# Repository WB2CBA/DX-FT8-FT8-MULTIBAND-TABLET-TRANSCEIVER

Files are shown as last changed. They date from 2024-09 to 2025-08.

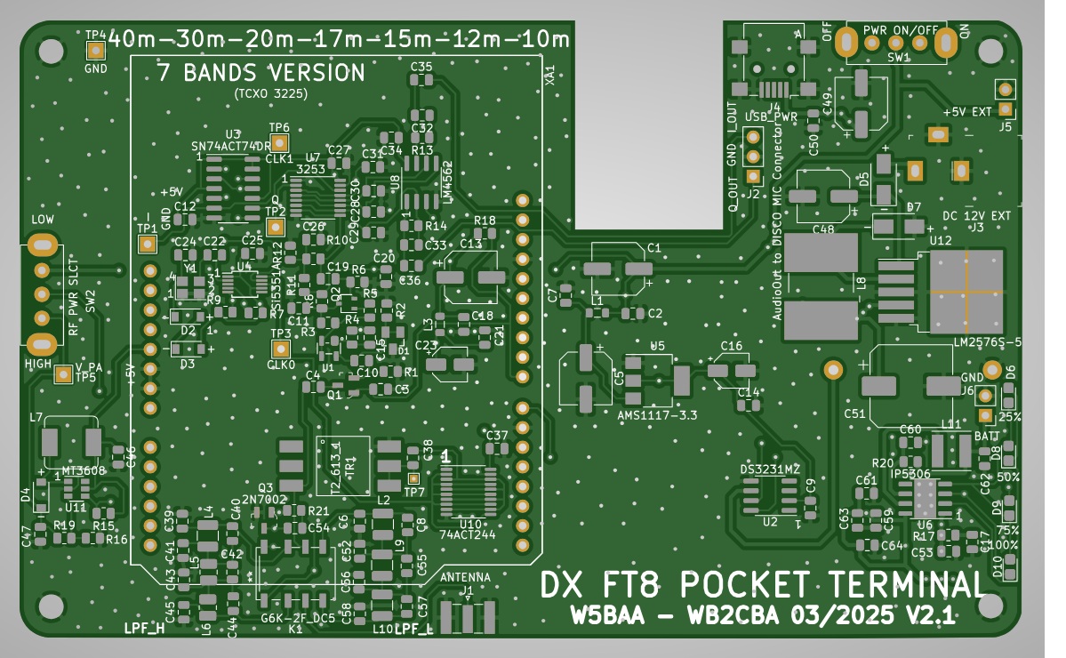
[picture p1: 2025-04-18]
DX FT8 7 Bands with BAT V2.1 component side PCB Layout.jpg

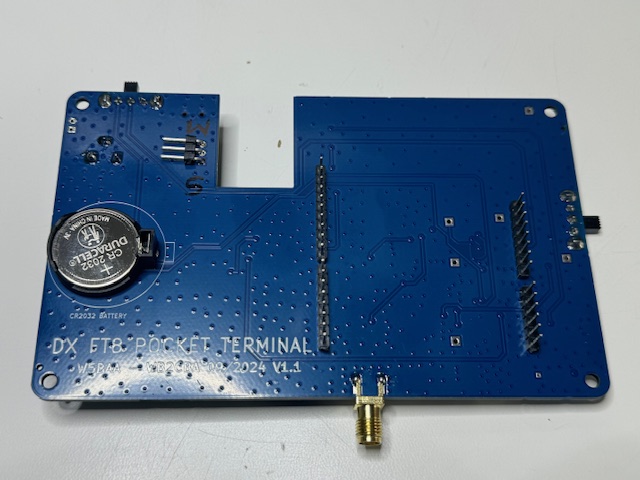
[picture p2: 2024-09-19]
DX FT8 7 BAND PCB INFORMATION/DX FT8 RF BOARD SOLDER SIDE.jpg

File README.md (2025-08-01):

# DX FT8  A MULTIBAND FT8 DIGITAL MODE 5 BANDS OR 7 BANDS TABLET TRANSCEIVER



FOR DX FT8 KIT INFORMATION AND ALL RELATED DISCUSSION YOU CAN JOIN BluQRP FORUM GROUP IN THIS LINK: https://groups.io/g/BluQRP
---------------------------------------------------------------------------------------------------------------------------------------------------
DX FT8 TRANSCEIVER BUILD AND OPERATION GUIDE CAN BE USED FOR OLDER 5 BAND VERSION AND 7 BAND VERSION without Internal Battery. 
---------------------------------------------------------------------------------------------------------------------------------------------------
ALL VERSIONS ARE IDENTICAL IN BUILD AND OPERATION DETAILS EXCEPT THE OPTIONAL INTERNAL BATTERY INSTALLATION ON V2.1 BMS 7 BAND BOARD.
---------------------------------------------------------------------------------------------------------------------------------------------------
DX FT8 TRANSCEIVER OPERATION GUIDE YOUTUBE VIDEO: https://www.youtube.com/watch?v=PcSgQS4a3Tk
----------------------------------------------------------------------------------------------------------------------------------------------------
DX FT8 TRANSCEIVER PROJECT is a collaboration between Charles(Charley)Hill, W5BAA and Barbaros(Barb)Asuroglu, WB2CBA.

DX FT8 Project is brain child of Charles(Charley)Hill, W5BAA. Charley designed and build various versions of GUI based FT8 Transceivers over the years. 

I was lucky enough to collaborate with Charley on 3 different versions of GUI FT8 Transceiver.

DX FT8 is the culmination of all that experience we gained from previous versions.

I can't thank enough Charley for his excellent GUI FT8 Firmware and his perseverance to create a standalone FT8 TABLET Transceiver.

It's a pleasure for me to collaborate with Charley,W5BAA, on hardware side, RF design and PCB design of DX FT8 Transceiver.

DX FT8 is an OPEN SOURCE PROJECT.
---------------------------------
DX FT8 is a FT8 Digital mode capable HF QRPp GUI (Graphical User Interface) based multiband Transceiver.

DX FT8 is abreviation for Digital Xceiver for FT8. 

Main aim of DX FT8 Transceiver Project is to create a highly portable stand-alone FT8 GUI Transceiver. Stand-alone aim is to create a user interface for working FT8 digital mode plus Multiband transceiver packed into one unit. 

This creates an advantage for carrying one GUI based FT8 operation capable Transceiver unit and no longer needs to carry a PC or a laptop or tablet for GUI interface operation for FT8 with a classic transceiver. 

This approach is quite appealing for smaller and lighter setups for backpacking for SOTA or POTA activations or as a travel transceiver with FT8.  

Here are some highlights on DX FT8 Specifications:

-	DX FT8 Transceiver GUI (Graphical User Interface) and processing power comes from ST Micro STM32F746 DISCO Evaluation board. This is a ARM CORTEX based evaluation board for STM32F746 microcontrollers with below outlined specifications: 

-	STM32F746NGH6 Arm® Cortex® core-based microcontroller with 1 Mbyte of Flash memory and 340 Kbytes of RAM, in BGA216 package 

-	4.3 inch RGB 480×272 color LCD-TFT with capacitive touch screen 

-	128-Mbit Quad-SPI Flash memory
 
-	DX FT8 Transceiver RF Board plugs into STM32F746 DISCO evaluation board to form the DX FT8 transceiver. 

-	DX FT8 Transceiver operates on 5 HF bands or 7 Bands depending on PCB type. Design files for both 5 band and 7 bands boards are posted in this github page.

-	These bands are:

For 5 Bands Board:
  
1 – 20m (14.074 MHz)

2- 17m (18.100 MHz)

3- 15m (21.074 MHz)

4- 12m (24.915 MHz)

5- 10m (28.074 MHz)

For 7 Bands Board:
  
1 – 40m (7.074 MHz)

2- 30m (10.136 MHz)

3 – 20m (14.074 MHz)

4- 17m (18.100 MHz)

5- 15m (21.074 MHz)

6- 12m (24.915 MHz)

7- 10m (28.074 MHz)

DX FT8 Transceiver has two RF Power Output Selection, LOW RF POWER and HIGH RF POWER which can be selected with the RF POWER Slide switch on the side of the transceiver.

40m	   372mW	       844mW

30m	   373mW	       843mW

20m	   380mW	       823mW

17m	   354mW	       762mW

15m	   314mW	       654mW

12m	   259mW	       520mW

10m	   231mW	       445mW

-	DX FT8 Transceiver can operate either from 5V USB power bank or any 1000mA capacity USB power source or by using the DC barrel Connector can be powered from 7V to 15V external power supply. A power supply source can be selected with DC POWER SELECT slide switch located on the side of the Transceiver. 

-	DX FT8 TRANSCEIVER uses an unconventional RF power Amplifier consisting of a TTL octal buffer IC and step up RF Transformer. There is no conventional MOSFET PA transistors. This creates an extremely resilient RF PA for failure due to high SWR or no antenna accidental operations.  This is an advantage for portable operations as antenna conditions can vary.

-	DX FT8 TRANSCEIVER incorporates a TAYLOE detector based Qudarature Sampling detector receiver with a high gain RF Preamplifier which outputs an I and Q phase output to STM32F746 DISCO board which generates true Upper Side Band (USB) SSB receive signal. 

-	A short video of DX FT8 in action:
  https://www.youtube.com/watch?v=8b2WOxESAVU
----------------------------------------------------------------------------------------------------------------------------------

DX FT8 FIRMWARE UPDATE HISTORY:

----------------------------------------------------------------------------------------------------------------------------------
DX FT8 Project Firmware Version 2.0.0 Release Notes: 29 JULY 2025
----------------------------------------------------------------------------------------------------------------------------------
V2.0.0 includes four major improvements over V1.9.7:

TX Queue: You can now click on multiple received messages in either QSO or Becn mode. The firmware will queue appropriate responses, automatically sort them, and transmit the best one for you. 
    
When calling CQ, replies from multiple stations will be queued automatically as well.

On Device Editing: Six buttons were added under the "Tune" page.

click one of these buttons to activate editing window:

CALL: YourCall or YourCall/P (Note: other prefix/suffix formats aren’t supported)

GRID: YourGrid

FREQ: 7074/.../28074 (optional) (Note: the firmware doesn’t validate frequency; make sure it's within the band. Use Band-/Band+ to switch bands.)

F1: Free Text 1 (optional) (Free Text also works for "CQ [A-ZZZZ] [YourCall] [YourGrid]")

F2: Free Text 2 (optional)

COM: Comments for the session (optional) (This will be added to each QSO in the .ADIF file)

Tap the same button again to finish editing and changes are saved to StationData.ini.

Auto-Generated StationData.ini: If no StationData.ini file is found on the SD card, the firmware will create one using an internal template. Just enter your callsign and grid on the device and you're ready to go—even with a blank SD card.

Showing worked QSOs for the current session: Tap the middle-right side of the screen to view worked QSOs, tap again to view the next page. (Tips: take photos as a backup in case the SD card fails)

--------------------------------------------------------------------
FOR SOURCE CODE PLEASE VISIT:
    https://github.com/chillmf/DX-FT8-Transceiver-Source-Code_V2
--------------------------------------------------------------------

DX FT8 3D PRINTED CASE FILES ADDED. A big Thank You to Dave,ZL1DMM for his excellent 3D case design.

 
------------------------------------------------------------------------------------------------------------------------------------------

- ACKNOWLEDGEMENT:

- We would like to thank Paul Winwood, G8KIG, Zhenxing han, N6HAN and Wei Cheng, AG6AQ for their contributions to develop and adding new features and cleaning the code of DX FT8 Firmware.

- DX-FT8 Firmware is inspired by work done by Karlis Goba, YL3JG. Here is a link to his website: https://github.com/kgoba/ft8_lib.

--------------------------------------------------------------------------------------------------------------------------------

---------------------------------------------------------------------------------------------------------------------------------
DUE TO TARIFFS DX FT8 KITS ARE GETTING EXTREMELY EXPENSIVE. WE STOPPED KITTING FOR THE TIME BEING TO WAIT FOR THE TARIFF SITUATION TO SETTLE. 
NO KITS WILL BE OFFERED AS OF 05/12/2025 UNTIL FURTHER NOTICE. SORRY FOR THE INCONVENIENCE. 
----------------------------------------------------------------------------------------------------------------------------------------------

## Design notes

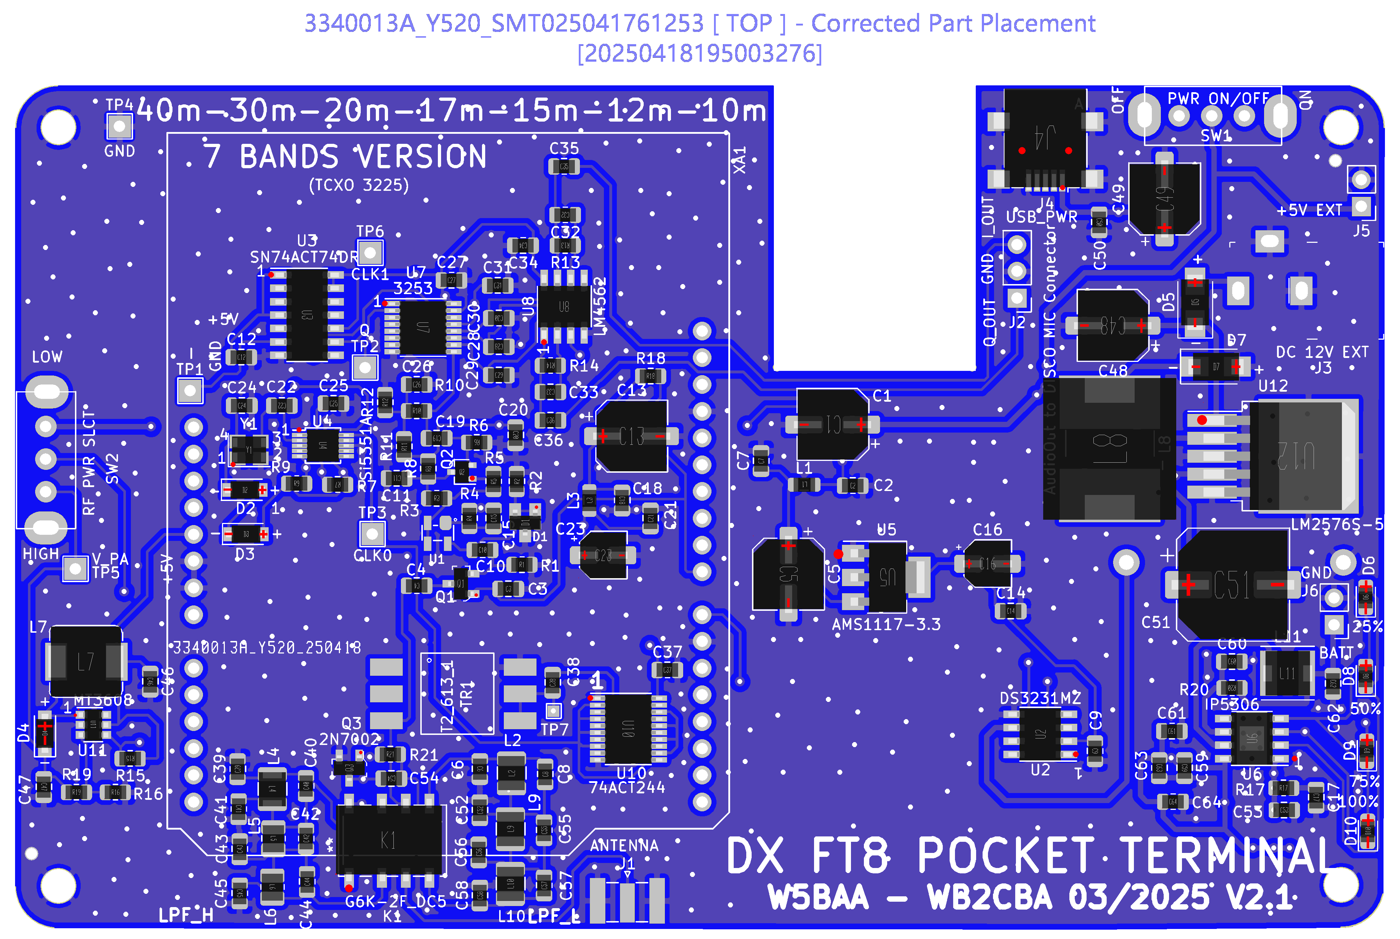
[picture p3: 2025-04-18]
DX FT8 7 BAND BMS V2.1 DFM ANALYSIS.png

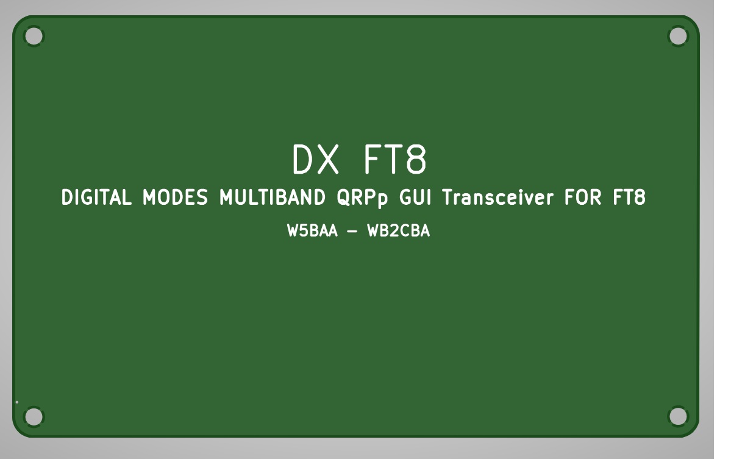
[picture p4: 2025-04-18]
DX FT8 7 Bands with BAT V2.1 BOTTOM PCB Layout.jpg

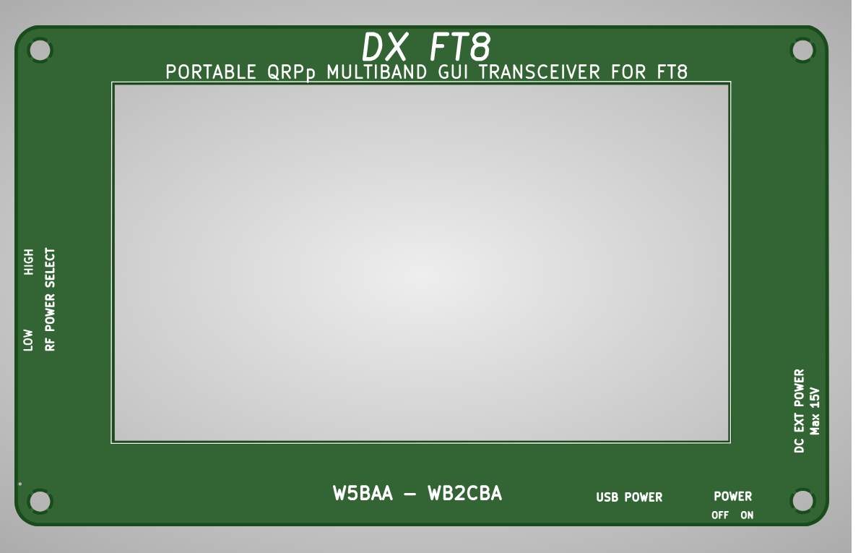
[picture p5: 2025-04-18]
DX FT8 7 Bands with BAT V2.1 TOP PCB Layout.jpg

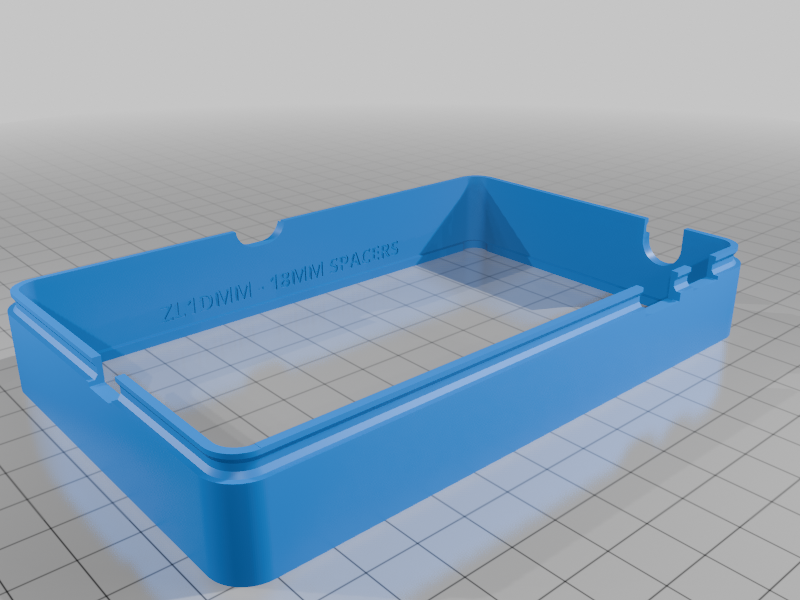
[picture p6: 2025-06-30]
DX FT8 3D CASE FILES/DXFT8_-_Case_Bottom_18mm_Bottom_Layer_Spacers.png

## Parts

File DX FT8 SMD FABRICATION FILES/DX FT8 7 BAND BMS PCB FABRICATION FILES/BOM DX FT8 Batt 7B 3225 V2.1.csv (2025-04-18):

Comment | Designator | Footprint | LCSC
47nF | C11,C20 | Capacitor_SMD:C_0805_2012Metric | C53134
100nF | C2,C7,C9,C12,C14,C18,C21,C22,C24,C25,C26,C27,C34,C37,C38,C50,C64 | Capacitor_SMD:C_0805_2012Metric | C28233
2.2nF | C15 | Capacitor_SMD:C_0805_2012Metric | C28260
10uF/16V | C16,C23 | Capacitor_SMD:CP_Elec_4x5.4 | C4747968
10uF | C17,C53 | Capacitor_SMD:C_0805_2012Metric | C15850
470nF | C28,C29,C30,C31,C54 | Capacitor_SMD:C_0805_2012Metric | C13967
1nF | C32,C33 | Capacitor_SMD:C_0805_2012Metric | C46653
1uF | C35,C36 | Capacitor_SMD:C_0805_2012Metric | C28323
100pF | C39 | Capacitor_SMD:C_0805_2012Metric | C37456
10nF | C3,C4,C10,C19 | Capacitor_SMD:C_0805_2012Metric | C1710
12pF | C40 | Capacitor_SMD:C_0805_2012Metric | C1792
180pF | C41 | Capacitor_SMD:C_0805_2012Metric | C3846504
150pF | C43 | Capacitor_SMD:C_0805_2012Metric | C107111
39pF | C8,C44 | Capacitor_SMD:C_0805_2012Metric | C107117
56pF | C42,C45 | Capacitor_SMD:C_0805_2012Metric | C1828
22uF | C46,C47,C59,C60,C61,C62,C63 | Capacitor_SMD:C_0805_2012Metric | C45783
100uF/16V | C1,C5,C13,C48,C49 | Capacitor_SMD:CP_Elec_6.3x7.7 | C3339
1000uF/16V | C51 | Capacitor_SMD:CP_Elec_10x10.5 | C970714
270pF | C52 | Capacitor_SMD:C_0805_2012Metric | C107106
82pF | C57 | Capacitor_SMD:C_0805_2012Metric | C113833
120pF | C55,C58 | Capacitor_SMD:C_0805_2012Metric | C527208
220pF | C6,C56 | Capacitor_SMD:C_0805_2012Metric | C107112
BAS70-04 | D1 | BAS70-04:SOT23 | C150242
100% | D10 | Diode_SMD:D_0805_2012Metric_Castellated | C84256
1N4148 | D2,D3 | Diode_SMD:D_SOD-123 | C81598
1N5817 | D4 | Diode_SMD:D_SOD-123 | C727113
25% | D6 | Diode_SMD:D_0805_2012Metric_Castellated | C84256
SS34 | D5,D7 | Diode_SMD:D_SMA | C8678
50% | D8 | Diode_SMD:D_0805_2012Metric_Castellated | C84256
75% | D9 | Diode_SMD:D_0805_2012Metric_Castellated | C84256
USB_PWR | J4 | Connector_USB:USB_Mini-B_Lumberg_2486_01_Horizontal | C2681563
G6K-2F_DC5 | K1 | G6K_2F:G6K-2F_Cor | C47190
100uH | L1,L3 | Inductor_SMD:L_0805_2012Metric | C223180
1uH | L11 | Inductor_SMD:L_Taiyo-Yuden_NR-50xx | C133189
560nH | L2 | Inductor_SMD:L_1210_3225Metric | C89030
330nH | L4 | Inductor_SMD:L_1210_3225Metric | C295307
270nH | L5,L6 | Inductor_SMD:L_1008_2520Metric | C295305
22uH | L7 | SubW:SubW_PWR_INDUCTOR | C497873
100uH | L8 | ADX_FOOTPRINT_LIBRARY:L_Bourns-SRN8040_8x8.15mm-MOD2 | C408533
470nH | L9,L10 | Inductor_SMD:L_1210_3225Metric | C89029
BSS123 | Q1 | digikey-footprints:SOT-23-3 | C513249
BFR93 | Q2 | Package_TO_SOT_SMD:SOT-323_SC-70 | C151481
2N7002 | Q3 | digikey-footprints:SOT-23-3 | C8545
1k | R1,R10 | Resistor_SMD:R_0805_2012Metric | C17513
10k | R11,R12 | Resistor_SMD:R_0805_2012Metric | C17414
2.7k | R13,R14 | Resistor_SMD:R_0805_2012Metric | C17530
3.9k | R15,R18,R21 | Resistor_SMD:R_0805_2012Metric | C17614
1.2k | R16 | Resistor_SMD:R_0805_2012Metric | C17379
2 ohm | R17 | Resistor_SMD:R_0805_2012Metric | C17606
12k | R19 | Resistor_SMD:R_0805_2012Metric | C17444
100k | R2 | Resistor_SMD:R_0805_2012Metric | C149504
0.5 ohm | R20 | Resistor_SMD:R_0805_2012Metric | C158119
470 | R3 | Resistor_SMD:R_0805_2012Metric | C17710
100 | R4 | Resistor_SMD:R_0805_2012Metric | C17408
22 | R5 | Resistor_SMD:R_0805_2012Metric | C17561
680 | R6 | Resistor_SMD:R_0805_2012Metric | C17798
4.7k | R7,R9 | Resistor_SMD:R_0805_2012Metric | C17673
33 | R8 | Resistor_SMD:R_0805_2012Metric | C17634
74ACT244 | U10 | Package_SO:TSSOP-20_4.4x6.5mm_P0.65mm | C6930
MT3608 | U11 | Package_TO_SOT_SMD:SOT-23-6 | C84817
LM2576S-5 | U12 | Package_TO_SOT_SMD:TO-263-5_TabPin3 | C347413
DS3231MZ | U2 | Package_SO:SOIC-8_3.9x4.9mm_P1.27mm | C107410
SN74ACT74DR | U3 | Package_SO:SOIC-14_3.9x8.7mm_P1.27mm | C6933
Si5351A | U4 | Package_SO:MSOP-10_3x3mm_P0.5mm | C504891
AMS1117-3.3 | U5 | Package_TO_SOT_SMD:SOT-223-3_TabPin2 | C6186
IP5306 | U6 | POCKET ATU V1:SO-8_3.9x4.9mm_P1.27mm | C181692
3253 | U7 | Package_SO:TSSOP-16_4.4x5mm_P0.65mm | C424399
LM4562 | U8 | Package_SO:SOIC-8_3.9x4.9mm_P1.27mm | C57367
26Mhz | Y1 | Crystal:Crystal_SMD_SeikoEpson_FA238-4Pin_3.2x2.5mm | C213404

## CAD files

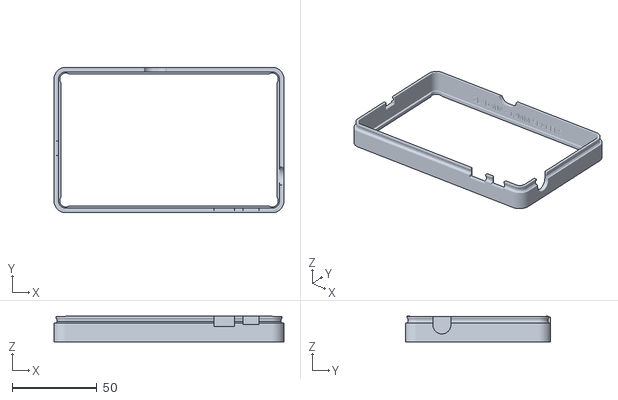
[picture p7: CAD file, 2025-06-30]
DX FT8 3D CASE FILES/DXFT8_-_Case_Bottom_12mm_Bottom_Layer_Spacers.stl
136.0 x 86.0 x 15.2

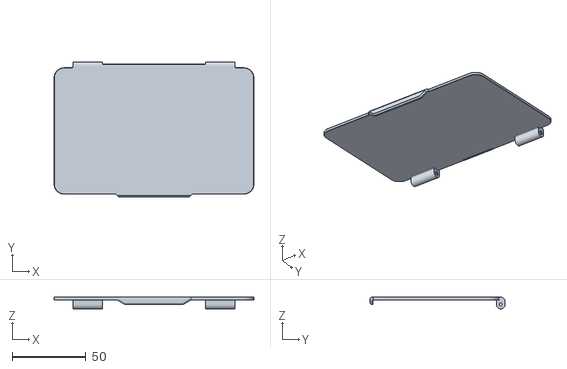
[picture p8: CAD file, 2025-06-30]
DX FT8 3D CASE FILES/DXFT8_-_Case_Door.stl
136.0 x 92.0 x 8.00

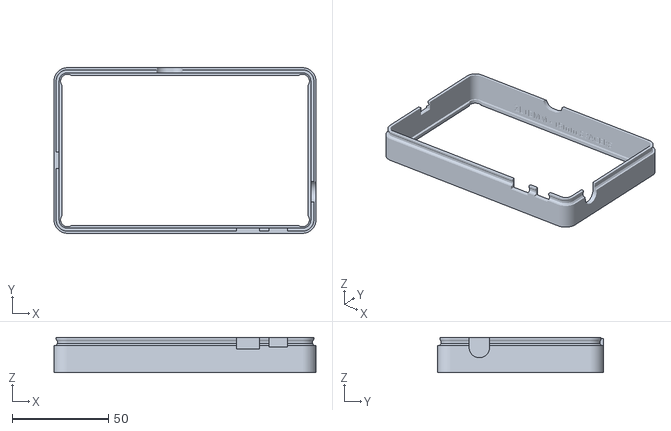
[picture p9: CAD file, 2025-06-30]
DX FT8 3D CASE FILES/DXFT8_-_Case_Bottom_15mm_Bottom_Layer_Spacers.stl
136.0 x 86.0 x 18.2

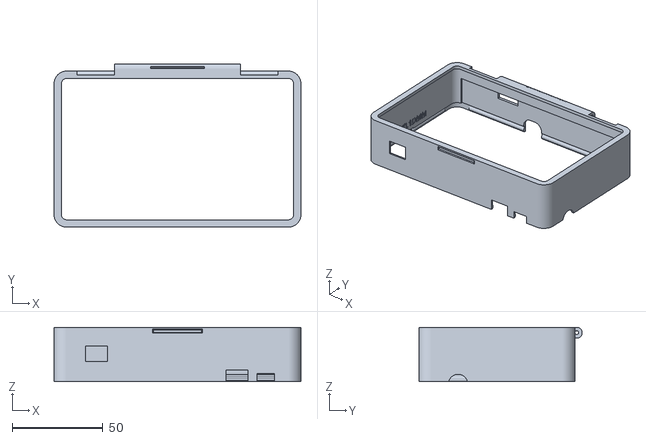
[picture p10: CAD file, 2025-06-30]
DX FT8 3D CASE FILES/DXFT8_-_Case_Top.stl
136.0 x 90.0 x 30.0

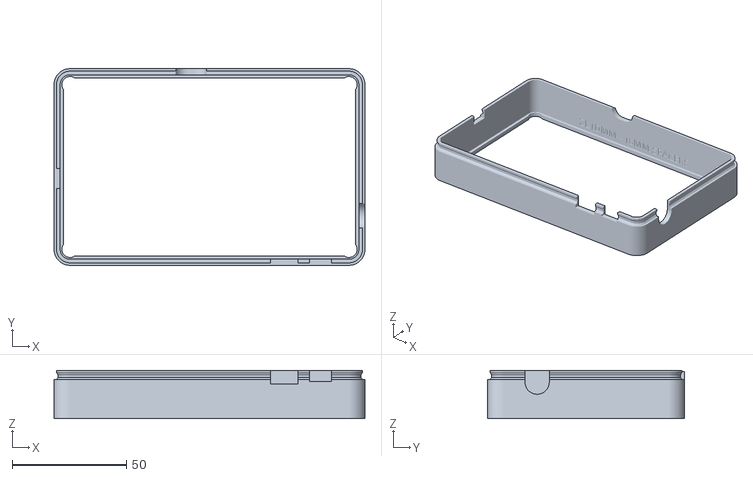
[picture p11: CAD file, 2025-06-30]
DX FT8 3D CASE FILES/DXFT8_-_Case_Bottom_18mm_Bottom_Layer_Spacers.stl
136.0 x 86.0 x 21.2

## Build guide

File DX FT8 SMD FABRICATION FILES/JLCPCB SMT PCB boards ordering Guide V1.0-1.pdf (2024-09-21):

# SMT PCB boards - JLCPCB ordering guide:

Now let’s talk about the most important subject! How we are going to get these SMD boards manufactured! Here is a short guide for ordering SMD manufactured boards from JLCPCB!

Surface mount parts might be intimidating for most of us. They need healthy eyes and steady hands to solder. This SMT pcb manufacturing service cures that problem by manufacturing PCBs and installing all smd parts on them in a controlled factory environment! An example of cost for this service: uSDX SOTA Main board will cost you less than 15 US Dollars each for a batch of 10 PCB orders including DHL shipping! This means a PCB with 85% of parts assembled including that SI5351 beast! The trick is the more units of pcb you order the less you pay for one pcb in cost.

The reason for that is there are certain one time fee costs JLCPCB adds to their invoice. Those are SMT setting up fee, extended parts fee etc. These are one time cost charges for each pcb order batch. So if we order 5 pieces of pcb that surcharge cost will be shared by 5 pcbs. If we order 30 pcbs then that surcharge will be divided by 30 and will be less per pcb. That’s why it is always order pcbs in larger quantities as a group buy. Ok how we will do this smt ordering business!

I’ll explain this as simple as possible in steps:

1- We will need Production files:
In order to place an order a SMT manufactured PCB from JLCPCB we need three files
– GERBER file (contains all the files to manufacture the PCB board itself)
– BOM File(contains all smd parts, their smd footprints and JLCPCB stock numbers for each part)
– Foot print position file (it is also called as centroid file – coordinates of each smd part on the pcb for pick and place robot)

All these files are included in each boards ZIP file under production file directory.

2- Create an account on www.jlcpcb.com. Follow instructions on their site.

3- After creating your account with all your credentials click on instant quote button

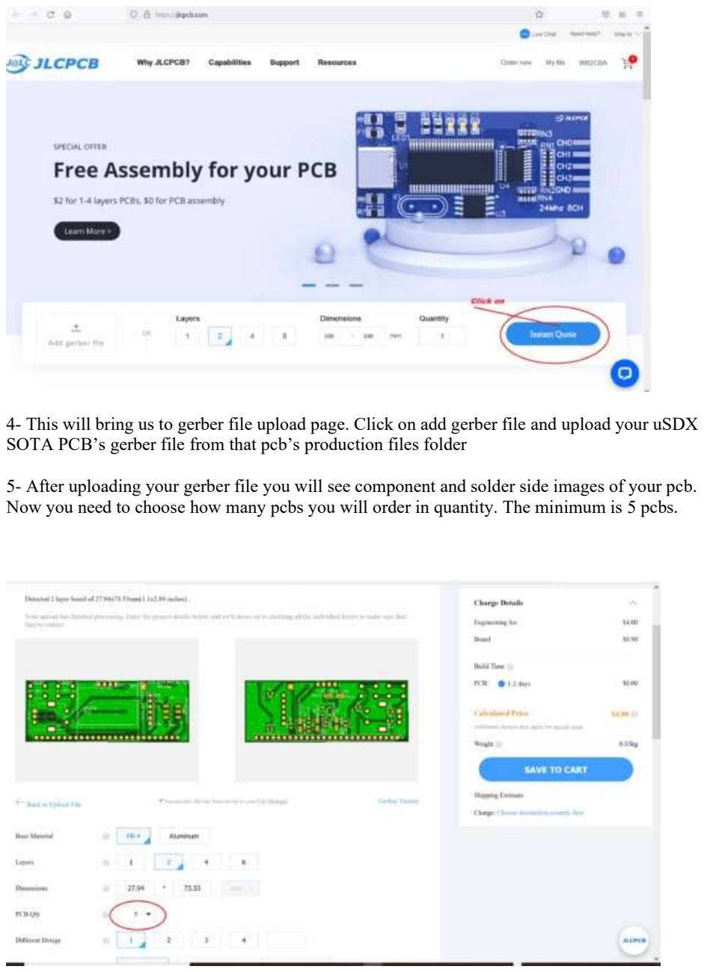
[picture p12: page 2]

4- This will bring us to gerber file upload page. Click on add gerber file and upload your uSDX SOTA PCB’s gerber file from that pcb’s production files folder

5- After uploading your gerber file you will see component and solder side images of your pcb. Now you need to choose how many pcbs you will order in quantity. The minimum is 5 pcbs.

6- Now scroll down the same gerber upload page until you see the Free SMT Assembly for your PCB slide switch which should be light grey inactive position. Now slide it to activate. You should see below screen with top and bottom sides of your PCB. In this case I used uSDX SOTA 128×64 OLED Display as an example. In this display smd populated side is bottom side so I chose assemble bottom side. Now without touching anything else first click on Confirm then click on NEXT.

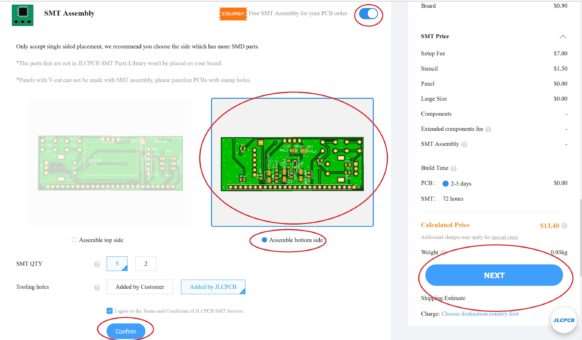
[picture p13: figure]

7- Now we will come to this next screen after clicking on NEXT. This is where we upload our BOM file and footprint position file which is marked as CPL button. These files are in your PCB’s production files. First click on Add BOM File button and upload BOM file from production files folder. Then click on Add CPL File Button and upload your footprint position file from your PCB’s production files.

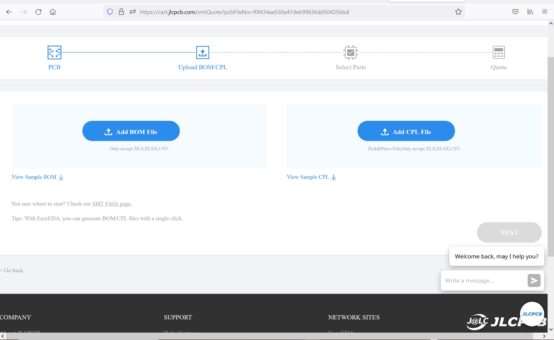
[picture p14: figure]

8- After uploading BOM and CPL files this is the screen which shows all the components of our PCB for SMT manufacturing. This table will show all the component part numbers, total number of each component that will be used for the whole batch of PCBs. Also total cost of each part for the whole batch of PCB order.

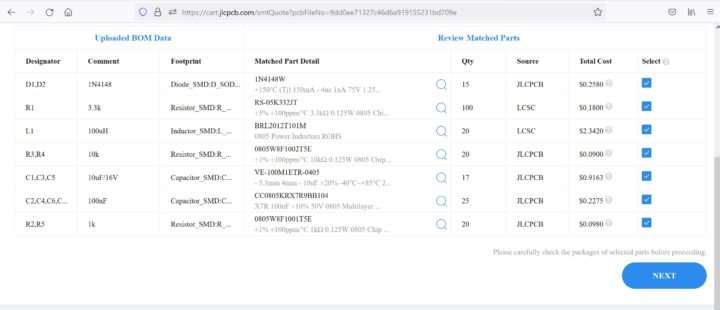
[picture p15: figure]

The most important column in this table is those blue check marks. If you see a blue check mark then it tells you that they have your components and those components have enough stock to manufacture your boards! If one or more parts is not in stock which can happen nowadays as there is chip shortage going on you might get an inventory shortage warning in place of blue check mark. Now JLCPCB does not have that part in stock and can’t pick and place that part and that part will be omitted from pick and place manufacturing. It’s not the end of the world! You can still get your pcb manufactured and hand solder those parts when you receive your pcbs.

Here is an example for that:

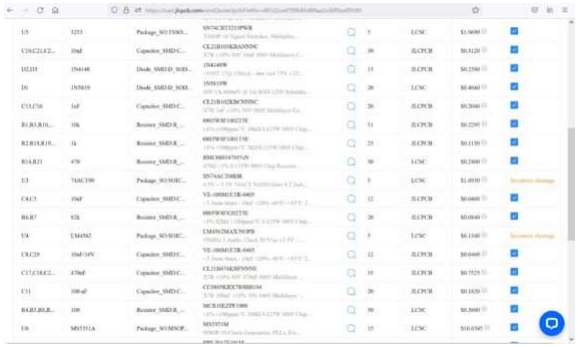
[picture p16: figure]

This is parts list for uSDX SOTA Main PCB. Two parts, 74ACT00DWR and LM4562 is out of stock. The rest of the parts are in stock so no problem with them. We will just order the PCBS and hand solder those parts afterwards. They are easy to solder smd parts.
Now click on NEXT to go to the next ordering screen.

9- This is the next screenshot you will come across which shows your PCB and virtual pick and place finished product layout of your pcb. There might be orientation errors in this PCB virtual parts layout time to time, don’t worry about that. JLCPCB will review your pcb layout and pick and place file and then match those positions. After you ordered your PCB for SMT manufacturing they will review it and correct those mismatches. After this review when you access your account you will see a DFM file icon. If you click on that it will show your previous and manufacturing virtual corrected layout.

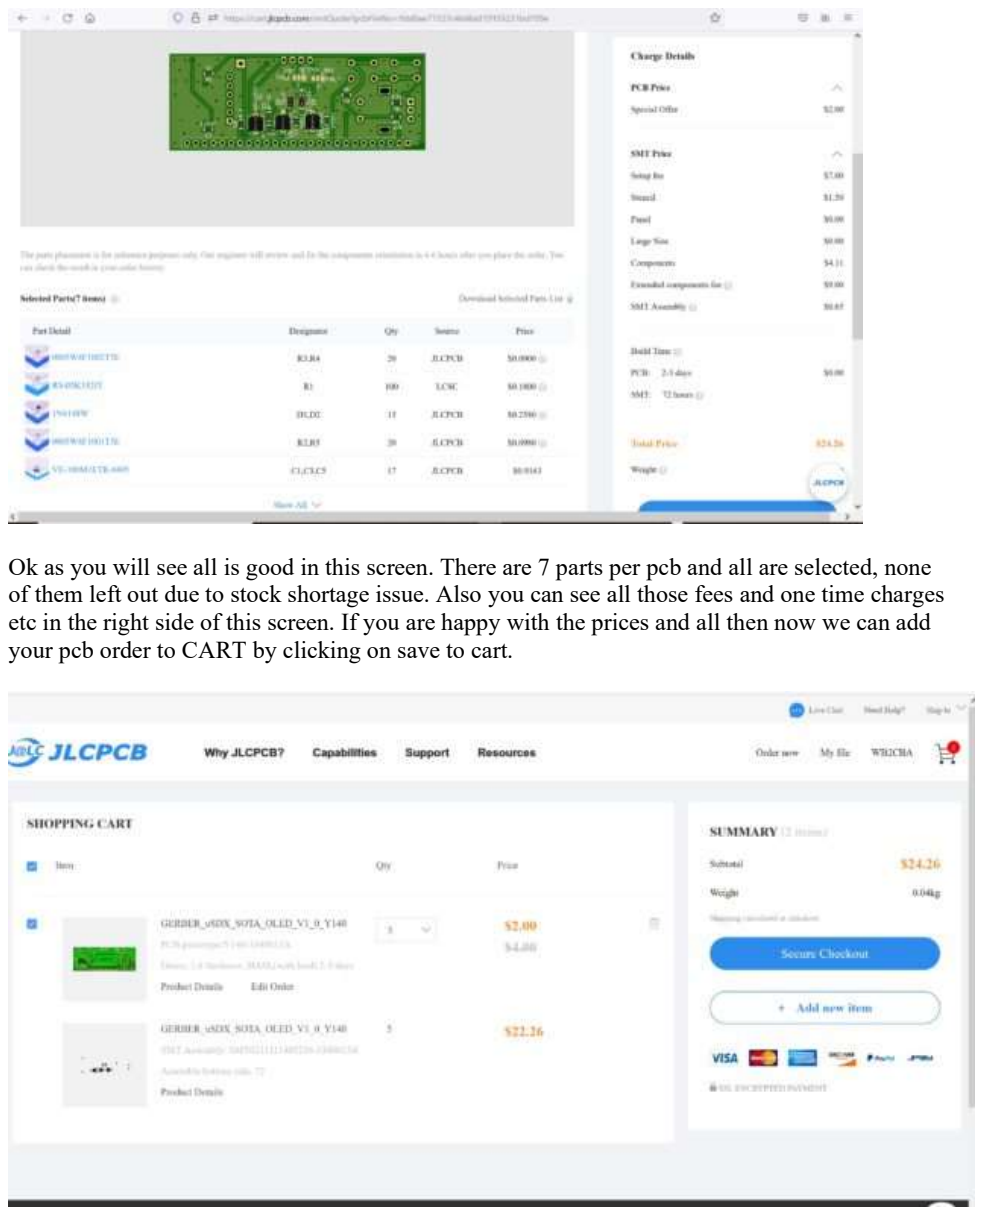
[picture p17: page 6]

Ok as you will see all is good in this screen. There are 7 parts per pcb and all are selected, none of them left out due to stock shortage issue. Also you can see all those fees and one time charges etc in the right side of this screen. If you are happy with the prices and all then now we can add your pcb order to CART by clicking on save to cart.

This CART screen will show your total cost for that ordered pcb batch. Now press on secure checkout and follow the procedure by verifying your address then shipment type and then payment etc.

Now let’s talk again about our nightmare case where some of the parts were out of stock!

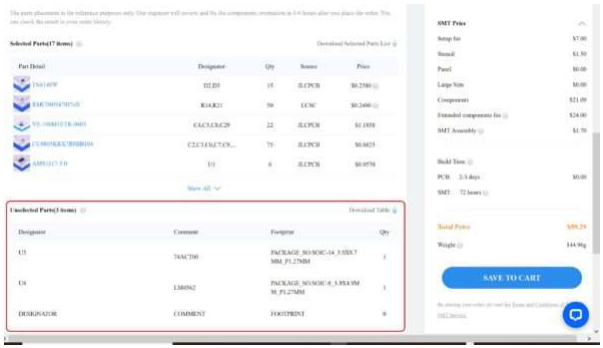
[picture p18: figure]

In uSDX SOTA Main board PCB case two parts were out of stock and we still advanced the order and clicked next. Now as outlined in red box those parts are out of production and not listed on main parts list and will not be shown on virtual smt mounted pcb layout. We can still go ahead with the order and save to cart and get main board pcbs manufactured and when we outsource those parts we can hand solder them. It’s not the end of the world!

Personally I encourage fellow DIY lover hams to give it a try on ordering uSDX SOTA boards smt manufactured from JLCPCB. You will be surprised how cheap they will be for an order of 10 boards. Even with minimum 5 boards is reasonable price. The biggest benefit is that 85% of the transceiver rig is coming to your door step already soldered in!

Barb WB2CBA
12/05/2021 NY, USA

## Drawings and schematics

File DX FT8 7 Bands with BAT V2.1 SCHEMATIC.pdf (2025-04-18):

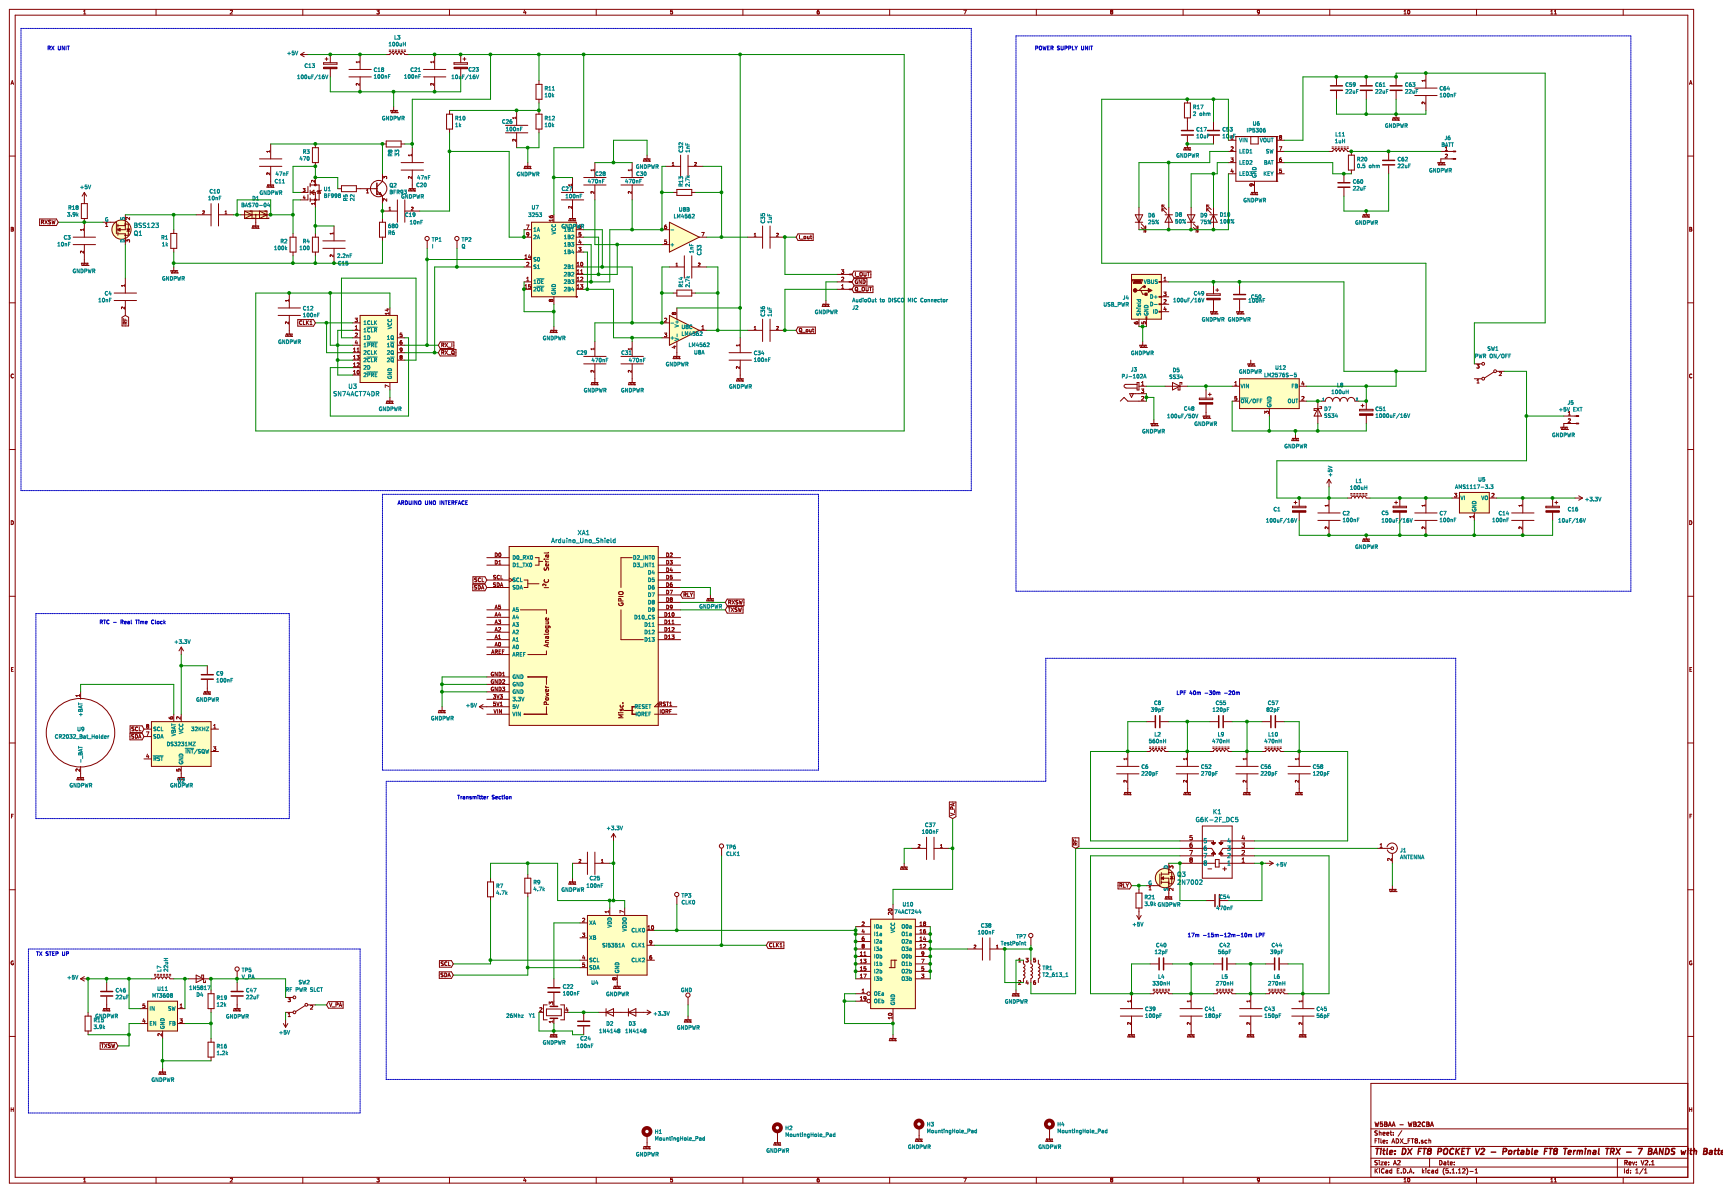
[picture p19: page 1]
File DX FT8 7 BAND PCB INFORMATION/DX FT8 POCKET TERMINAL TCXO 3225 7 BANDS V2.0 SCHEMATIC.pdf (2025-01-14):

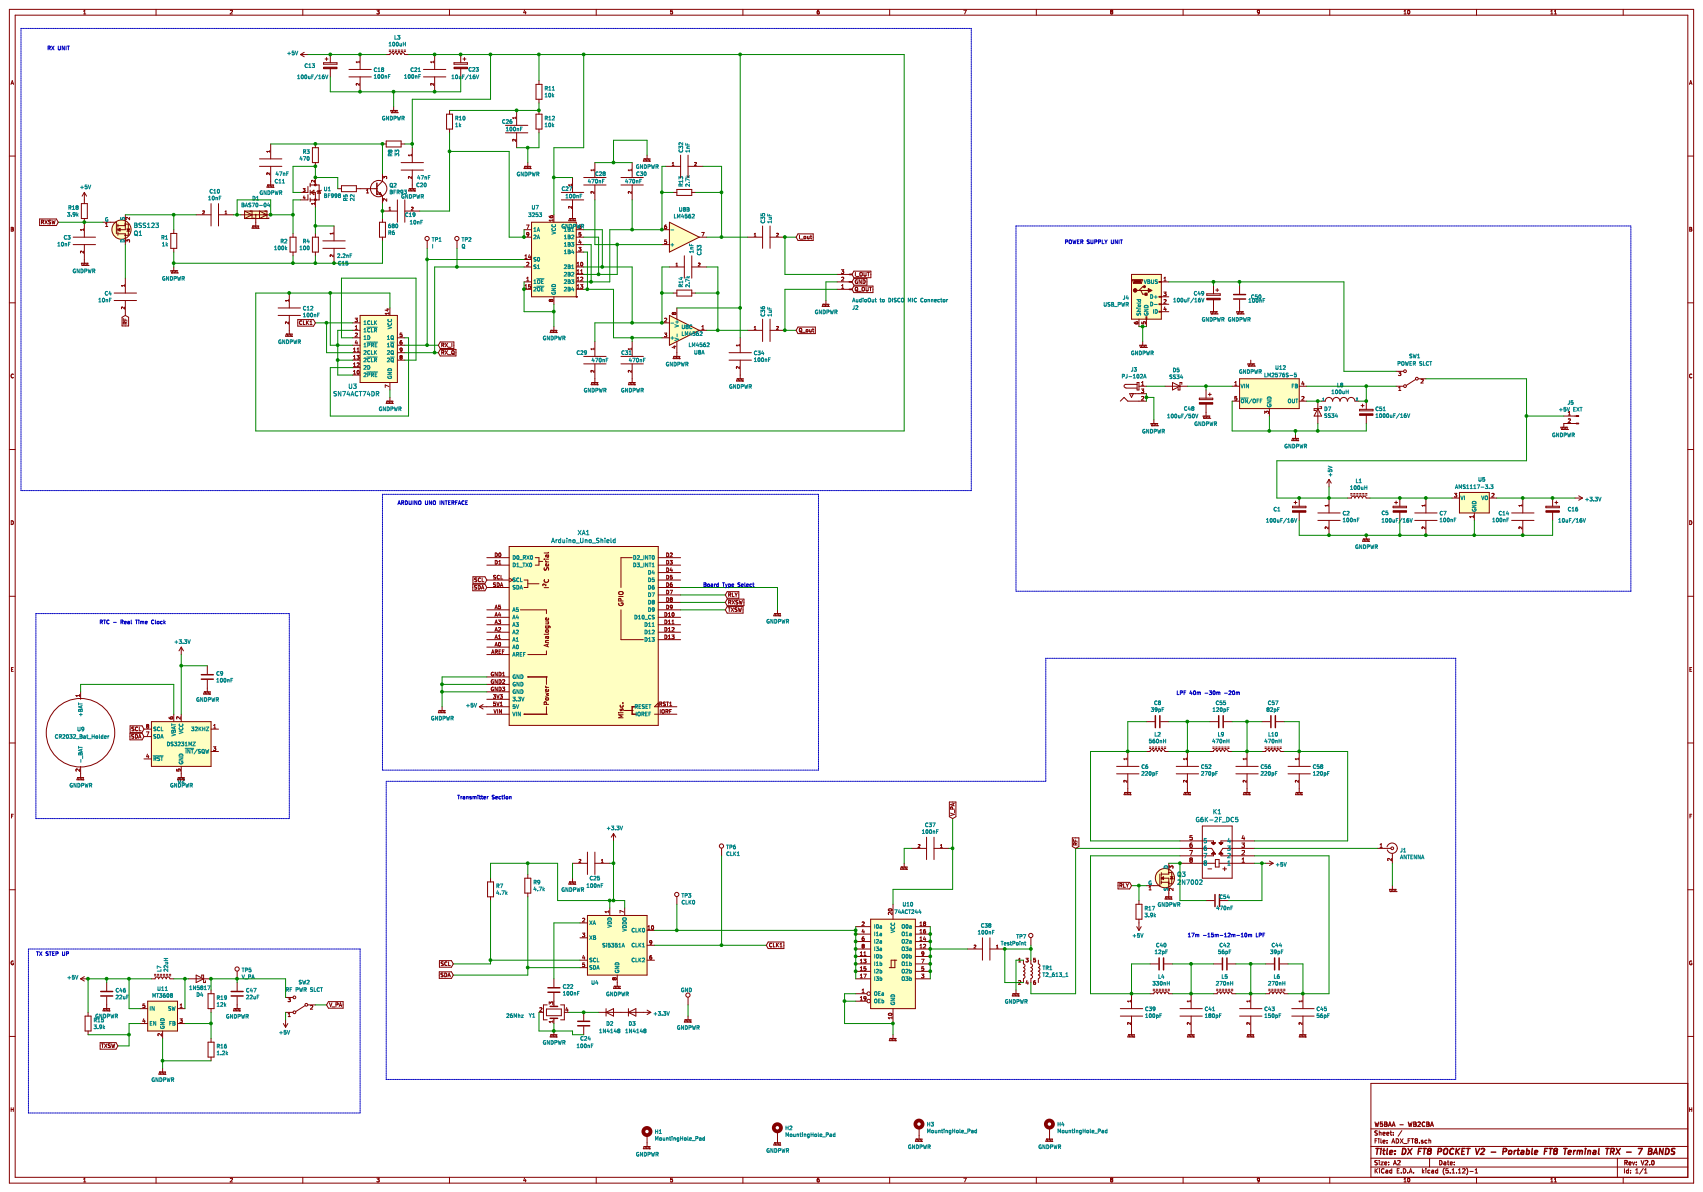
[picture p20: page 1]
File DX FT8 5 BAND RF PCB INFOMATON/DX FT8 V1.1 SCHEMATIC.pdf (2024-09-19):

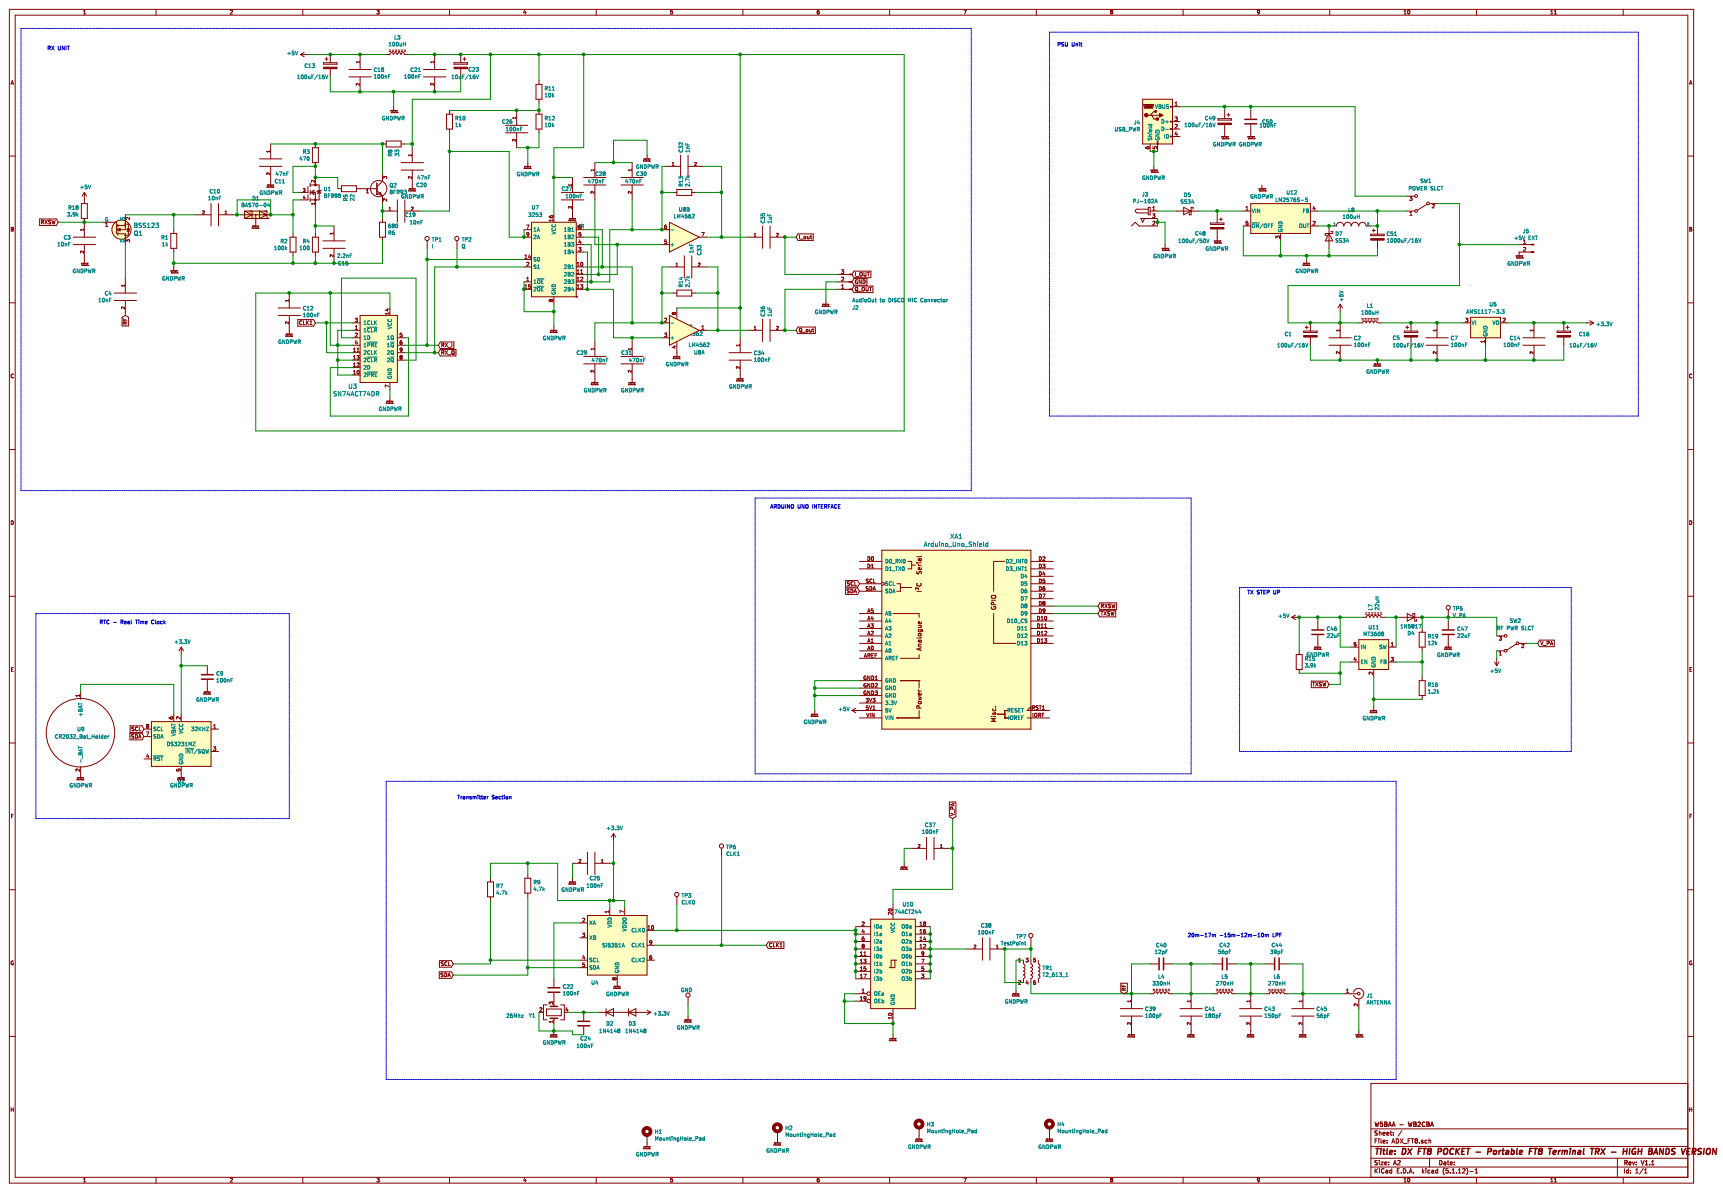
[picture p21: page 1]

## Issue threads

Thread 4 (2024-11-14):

Power requirements

RChadwick7, 2024-11-14:
I don't have a DX-FT8 yet but it's on the way. I have a question about power. I'll probably add a Li-Ion battery and BMS. The docs say 5V at 1A. Is that a minimum? Should I provide 2+ Amps? Will a higher voltage be better, or will a regulator just knock it down to 5V?

RChadwick7, 2024-11-17:
Nevermind, I found the schematic and found my answers. 5V.

Closed 2024-11-17.

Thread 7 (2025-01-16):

Battery Management on board

RChadwick7, 2025-01-16:
There appears to be plenty of room to tuck a thin Li-Po battery between the layers. It would be extra beneficial if there was a BMS on board, or even just unpopulated pads so those of us who want to add a battery can do so. There are plenty of single chips that will handle charging, discharge protection, stepping up to 5V, even a battery level monitor. There are also tons of small modules from places like AliExpress but not as elegant as being on board.

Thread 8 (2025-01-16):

Invalid Call or Locator

RChadwick7, 2025-01-16:
Firmware 1.8 with the old 5 band board. 32GB Sandisk MicroSD
No matter what call or locator I use, even W5BAA:EM00, I get Invalid Call or Locator. I have reformatted and recreated the StationData.txt with the same results

wcheng95, 2025-01-16:
Try to put a space before W5BAA, it may do the trick because the standard callsign is 2x3

RChadwick7, 2025-01-17:
Thanks for the response. The space didn't help. However, I did finally get it working. First, I formatted a 16GB MicroSD and tried that one. It still didn't work, but something new happened. Two new files appeared (for settings and ADIF) which led me to believe I was getting closer. While the StationData.txt was originally capitalized, the new MicroSD had it not capitalized. I capitalized the S and D, and it now works.

So:

1) Potential issues over 16GB

2) StationData.txt needs to be exact. stationdata.txt isn't good enough.

g8kig, 2025-01-17:
> Try to put a space before W5BAA, it may do the trick because the standard callsign is 2x3

Sorry, no this is not necessary.

g8kig, 2025-01-17:
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

On Windows the case of file names is ignored, on Linux and many other operating systems it is significant.
Can you confirm that your 32GB SDCard is formatted as Fat32 please?

RChadwick7, 2025-01-19:
Sorry about the delay. I can confirm the 32GB MicroSD is FAT32.

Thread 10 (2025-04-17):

Case design, design rule violate at JLCPCB printing service

rspanbauer, 2025-04-17:
I submitted the stl files for the case to JLCPCB yesterday.  Upon review, they identified an issue "wall thickness of those indicated red area is too thin, which has high risks of loss, deformation ,crack, or damage during the printing process".  I've included the rendering the JCLPCB engineer provided.

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

I didn't see the original cad files in the repo, and searching for ZL1DMM contact info proved fruitless.

WB2CBA, 2025-04-17:
Rick,Don’t worry about jlcpcb warning. Just accept the risk and let them print. I ordered 20 cases of DX FT8 from jlcpcb and all turned up good.Jlcpcb has a policy to warn any thickness below 2mm. Stl files are in this directory on dxft8 github:DX-FT8-FT8-MULTIBAND-TABLET-TRANSCEIVER/DX FT8 3D CASE FILES at main · WB2CBA/DX-FT8-FT8-MULTIBAND-TABLET-TRANSCEIVERgithub.com73Barb WB2CBAOn Apr 17, 2025, at 07:57, Rick Spanbauer ***@***.***> wrote:
  I submitted the stl files for the case to JLCPCB yesterday.  Upon review, they identified an issue "wall thickness of those indicated red area is too thin, which has high risks of loss, deformation ,crack, or damage during the printing process".  I've included the rendering the JCLPCB engineer provided.
dx_ft8_case_issue.png (view on web)
I didn't see the original cad files in the repo, and searching for ZL1DMM contact info proved fruitless.—Reply to this email directly, view it on GitHub, or unsubscribe.You are receiving this because you are subscribed to this thread.Message ID: ***@***.***>

rspanbauer created an issue (WB2CBA/DX-FT8-FT8-MULTIBAND-TABLET-TRANSCEIVER#10)
I submitted the stl files for the case to JLCPCB yesterday.  Upon review, they identified an issue "wall thickness of those indicated red area is too thin, which has high risks of loss, deformation ,crack, or damage during the printing process".  I've included the rendering the JCLPCB engineer provided.
dx_ft8_case_issue.png (view on web)
I didn't see the original cad files in the repo, and searching for ZL1DMM contact info proved fruitless.

—Reply to this email directly, view it on GitHub, or unsubscribe.You are receiving this because you are subscribed to this thread.Message ID: ***@***.***>

rspanbauer, 2025-04-18:
Thanks Barb, will do.  I'm going to try a print at home here also.

Wish the author had supplied the original cad files, would have been a
nice example.

On Thu, Apr 17, 2025 at 12:55 PM Barb - WB2CBA ***@***.***>
wrote:

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

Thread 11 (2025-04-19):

different ft8 frequency

ekiojp, 2025-04-19:
Hi,
Is there any way to specify FT8 band frequency manually or override default one? Maybe by setting a file in SD or via Tune?
For my usecase, Japan domestic FT8 in 40m is 7.041Mhz

WB2CBA, 2025-04-19:
Hi,Not possible as of now but this is a good point to consider in firmware. I’ll pass it to firmware guys to consider. May be they can add an option button in configuration screen.73Barb WB2CBAOn Apr 19, 2025, at 11:33, Emilio ***@***.***> wrote:
  Hi,
Is there any way to specify FT8 band frequency manually or override default one? Maybe by setting a file in SD or via Tune?
For my usecase, Japan domestic FT8 in 40m is 7.041Mhz—Reply to this email directly, view it on GitHub, or unsubscribe.You are receiving this because you are subscribed to this thread.Message ID: ***@***.***>

ekiojp created an issue (WB2CBA/DX-FT8-FT8-MULTIBAND-TABLET-TRANSCEIVER#11)
Hi,
Is there any way to specify FT8 band frequency manually or override default one? Maybe by setting a file in SD or via Tune?
For my usecase, Japan domestic FT8 in 40m is 7.041Mhz

—Reply to this email directly, view it on GitHub, or unsubscribe.You are receiving this because you are subscribed to this thread.Message ID: ***@***.***>

ekiojp, 2025-04-20:
thanks, that will be appreciated. Will test other bands
